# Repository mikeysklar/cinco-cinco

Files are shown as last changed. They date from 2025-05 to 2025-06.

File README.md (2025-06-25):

# Cinco-Cinco  
*A 5-Key Wireless Chording Keyboard*

Cinco-Cinco is a low-profile chording keyboard that uses just **five
keys** to emulate a full keyboard by combining keypresses into
chords and utilizing **seven layers**.

I’ve spent the last year building pocket keyboards. My
[BUBBY](https://github.com/mikeysklar/bubby) is a daily carry which
I use for todo lists. It made me enjoy typing with one hand to the
point that I wanted a desktop version, which is what you see here.

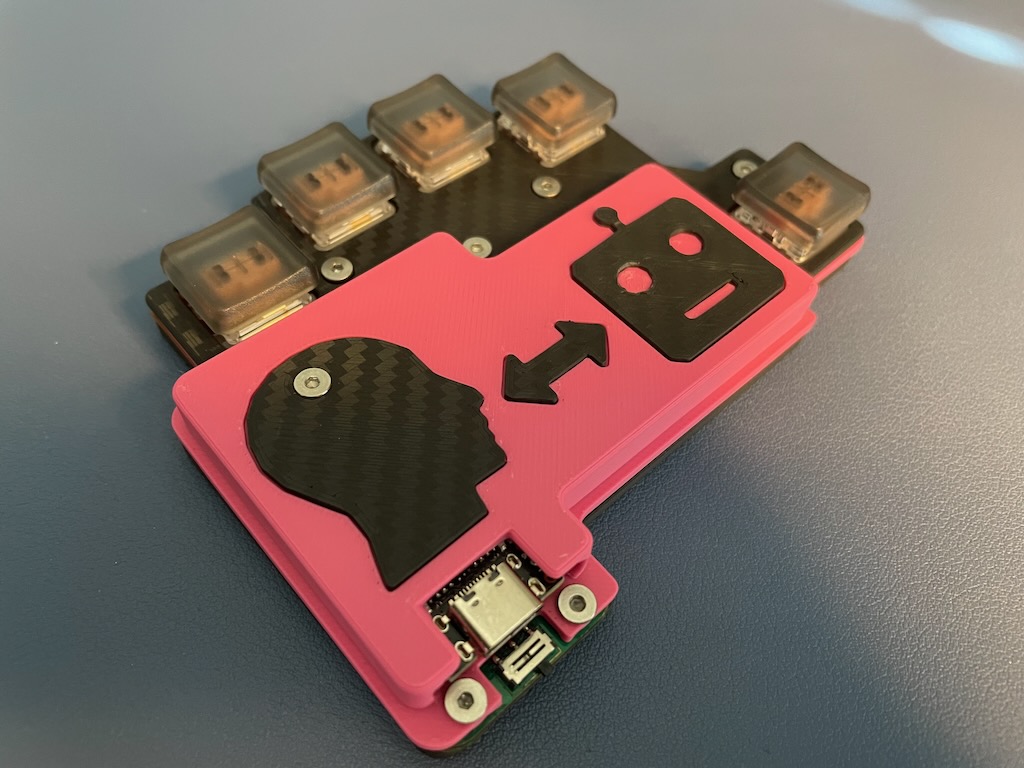
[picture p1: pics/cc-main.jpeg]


## Table of Contents

- [Introduction](#introduction)
- [Hardware Highlights](#hardware-highlights)
  - [Case Design](#case-design)
  - [Mechanical Switch Choice](#mechanical-switch-choice)
  - [Chording Software](#chording-software)
- [CircuitPython Compatibility](#circuitpython-compatibility)
- [Design Files & Software Versions](#design-files--software-versions)
- [Typing Speed](#typing-speed)
- [Layer Maps](#layer-maps)
  - [Layer 1: Letters](#layer-1-letters)
  - [Layer 2: Numbers](#layer-2-numbers)
  - [Layer 3: Whitespace & Delimiters](#layer-3-whitespace--delimiters)
  - [Layer 4: Modifiers & Navigation](#layer-4-modifiers--navigation)
  - [Layer 5: Mouse Control / Media](#layer-5-mouse-control--media)
  - [Layer 6: Media](#layer-6-media)
  - [Layer 7: F1 - F12](#layer-7-F1---F12)
- [BOM](#bill-of-materials)

---

## Introduction

Computing is rapidly changing. We are moving away from sitting at
desks and staring at screens. Smart glasses and watches let us
consume information on the go. Phones, which have taken too much
of our attention, no longer need to be our primary method of
communication.

**The keys are key**

Chording opens up a future of input that is compact, discreet, and
mobile. This same keyboard can also enhance desktop productivity,
allowing CAD users and creatives to use one hand for keyboard
shortcuts while the other handles precise mouse movements.

Cinco-Cinco uses just **five keys**, but can generate over 107
different key combos, including mouse actions. The thumb button
switches between **seven layers**—alphabets, numbers, punctuation,
and more. The layout is based on a modified SAIE layout, optimized so 
the most common letters require minimal finger effort.

At first, I wasn’t sure cramming so much into the thumb key would
work well. But with careful timing and logic in the firmware, it
switches layers smoothly without getting in the way.

---

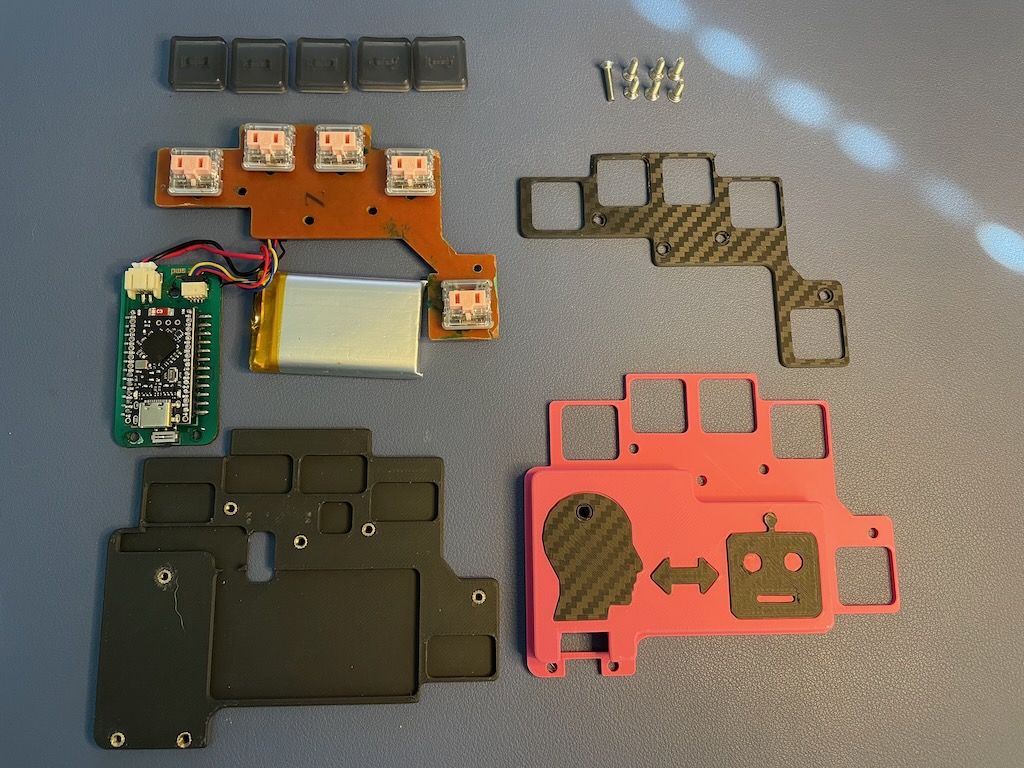
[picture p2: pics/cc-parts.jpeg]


## Hardware Highlights

- **I2C STEMMA QT connector** for plug-and-play support for different controllers  
- **Two PCB system**: one controller board and one keypad connected via STEMMA QT cable  
- **Hardware-based key detection**: MCP23008 GPIO expander running at 400 kHz for fast, accurate chord detection  
- **BLE-compatible microcontrollers**: Tested with nRF52840  
- **1200mAh battery** integrated into the case to hold keypad in place and reduce charging frequency  



### Case Design

The case is built as a three-layer sandwich. The base has cutouts
to keep components low profile and includes heat-set inserts to
secure the mid and top layers. The PCBs have matching holes for
alignment and locking, ensuring a secure fit.

Flat, countersunk screws keep the top flush. The “Human Machine”
inlay was added late to break up the large pink area and has become
a distinctive feature.

### Mechanical Switch Choice

I chose Kailh PG1350 CHOC switches for their availability and easy
installation. Their low-profile design lets all components fit on
the PCB’s bottom side, simplifying SMT assembly. I’ve tried pink,
red, and robin egg blue switches—the blue ones feel best to type
on, despite needing more force, and they look nice too.

### Chording Software

The firmware works hard to register chords accurately despite early
challenges with false triggers and duplicates. It waits for the
first key release before registering a chord, allowing for sloppy
or staggered key presses without mistakes. It doesn’t wait for all
keys to be released — once a key lifts, the chord buffer clears,
letting you move on quickly.

---

## CircuitPython Compatibility

- **Tested with CircuitPython**: Version 9.2.8
- Library installation process if MacOS is used (delete the ._ libs)

```
circup install adafruit_ble adafruit_bus_device adafruit_hid
cd /Volumes/CIRCUITPY
find . -type f -name '._*' -delete

circup install adafruit_displayio_ssd1306 adafruit_display_text adafruit_ssd1306 adafruit_mcp230xx

cd /Volumes/CIRCUITPY
find . -type f -name '._*' -delete
```

---

## Design Files & Software Versions

### PCB & Schematic Files
- **KiCad**: Version 9

**Cinco-Cinco board (`cinco-cinco/` folder):**
- [`cinco-cinco.kicad_sch`](cinco-cinco/cinco-cinco.kicad_sch)
- [`cinco-cinco.kicad_pcb`](cinco-cinco/cinco-cinco.kicad_pcb)

**nnv2-smd board (`nnv2-smd/` folder):**
- [`nnv2-smd.kicad_sch`](nnv2-smd/nnv2-smd.kicad_sch)
- [`nnv2-smd.kicad_pcb`](nnv2-smd/nnv2-smd.kicad_pcb)

### Case Files (`cad/` folder)
- **FreeCAD**: Version 1.x
- [`case.FCStd`](cad/case.FCStd)

**STL files for 3D printing:**
- [`case-top-cvr.stl`](cad/case-top-cvr.stl)
- [`case-mid-cvr.stl`](cad/case-mid-cvr.stl)
- [`case-lwr-cvr.stl`](cad/case-lwr-cvr.stl)

**STEP files for 3D viewing:**
- [`case-top-cvr.step`](cad/case-top-cvr.step)
- [`case-mid-cvr.step`](cad/case-mid-cvr.step)
- [`case-lwr-cvr.step`](cad/case-lwr-cvr.step)
- [`case-cinco-cinco.step`](cad/case-cinco-cinco.step)
- [`case-bat1200.step`](cad/case-bat1200.step)
- [`case-nnv2-smd.step`](cad/case-nnv2-smd.step)

All hardware design files are open source and located in the `pcb/` and `cad/` directories of this repository.

---

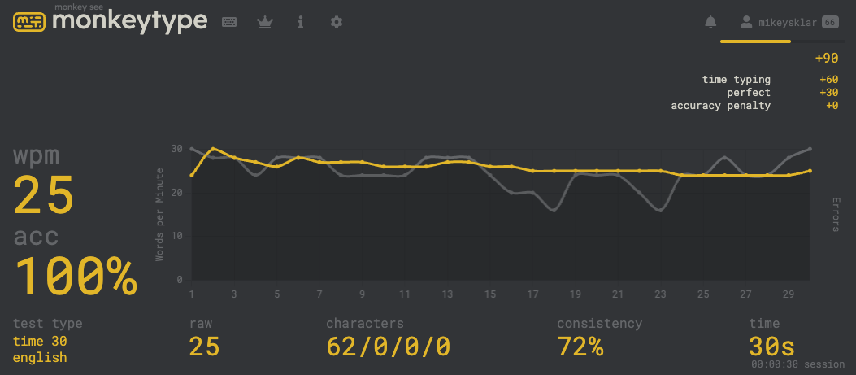
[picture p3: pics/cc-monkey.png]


## Typing Speed

Typing speed on the cinco is ~25 WPM. It is fast enough to not be frustrated. Slow enough to improve on.

That is about the same as my typing speed:

* thumb typing speed on my phone
* one handed on a qwerty full size keyboard

---

## Layer Maps

Each layer uses unique key combinations (chords) from the 5 keys (positions 0–4).

| Finger | Key Index |
|:---|:---|
| Thumb  | 4 |
| Pinky  | 3 |
| Ring | 2 |
| Middle | 1 |
| Fore | 0 |

## Layer 1: Letters 

| Key | Pky | Rng | Mid | Idx | Thm | Chord |
|---|:---:|:---:|:---:|:---:|:---:|---|
| A | |  x  | | | | (2,) |
| B |  x  | | | |  x  | (3,4) |
| C |  x  | | |  x  | | (0,3) |
| D | |  x  |  x  |  x  | | (0,1,2) |
| E | | | |  x  | | (0,) |
| F | |  x  |  x  | |  x  | (1,2,4) |
| G | | |  x  | |  x  | (1,4) |
| H | |  x  | | |  x  | (2,4) |
| I | | |  x  | | | (1,) |
| J | |  x  |  x  |  x  |  x  | (0,1,2,4) |
| K |  x  | |  x  | |  x  | (1,3,4) |
| L |  x  | |  x  | | | (1,3) |
| M | | | |  x  |  x  | (0,4) |
| N | |  x  |  x  | | | (1,2) |
| O | |  x  | |  x  | | (0,2) |
| P |  x  |  x  |  x  | | | (1,2,3) |
| Q |  x  |  x  |  x  |  x  |  x  | (0,1,2,3,4) |
| R | | |  x  |  x  | | (0,1) |
| S | | | | |  x  | (3,) |
| T |  x  |  x  | | | | (2,3) |
| U |  x  |  x  |  x  |  x  | | (0,1,2,3) |
| V |  x  |  x  | | |  x  | (2,3,4) |
| W | |  x  | |  x  |  x  | (0,2,4) |
| X |  x  | | |  x  |  x  | (0,3,4) |
| Y | | |  x  |  x  |  x  | (0,1,4) |
| Z |  x  |  x  |  x  | |  x  | (1,2,3,4) |
| BACKSPACE |  x  | |  x  |  x  | | (0,1,3) |
| SPACE |  x  |  x  | |  x  | | (0,2,3) |
    
## Layer 2: Numbers and Arrows 

| Action | Pky | Rng | Mid | Idx | Thm | Chord |
|---|:---:|:---:|:---:|:---:|:---:|---|
| ONE | | | |  X  | | (0,) |
| TWO | | |  X  | | | (1,) |
| THREE | |  X  | | | | (2,) |
| FOUR |  X  | | | | | (3,) |
| FIVE | | |  X  |  X  | | (0, 1) |
| SIX | |  X  |  X  | | | (1, 2) |
| SEVEN |  X  |  X  | | | | (2, 3) |
| EIGHT | |  X  | |  X  | | (0, 2) |
| NINE |  X  | |  X  | | | (1, 3) |
| ZERO | |  X  |  X  |  X  | | (0, 1, 2) |
| UP_ARROW | | | |  X  |  X  | (0, 4) |
| DOWN_ARROW  | | |  X  | |  X  | (1, 4) |
| RIGHT_ARROW | |  X  | | |  X  | (2, 4) |
| LEFT_ARROW  |  X  | | | |  X  | (3, 4) |
| PAGE_UP | | |  X  |  X  |  X  | (0, 1, 4) |
| PAGE_DOWN |  X  |  X  | | |  X  | (2, 3, 4) |
| END | |  X  |  X  |  X  |  X  | (0, 1, 2, 4) |
| DELETE | |  X  | |  X  |  X  | (0, 2, 4) |
| INSERT |  X  | |  X  | |  X  | (1, 3, 4) |
| HOME |  X  |  X  |  X  | |  X  | (1, 2, 3, 4) |

## Layer 3: Whitespace & Delimiters

| Action | Pky | Rng | Mid | Idx | Thm | Chord |
| --- | :-: | :-: | :-: | :-: | :-: | --- |
| ESCAPE | | | |  X  | | (0,) |
| TAB | | |  X  | | | (1,) |
| PERIOD | |  X  | | | | (2,) |
| MINUS |  X  | | | | | (3,) |
| FORWARD_SLASH  |  X  |  X  | | | | (2, 3) |
| ENTER | | |  X  |  X  | | (0, 1) |
| COMMA | |  X  | |  X  | | (0, 2) |
| LEFT_BRACKET |  X  | |  X  | | | (1, 3) |
| RIGHT_BRACKET  |  X  | | |  X  | | (0, 3) |
| BACKSLASH |  X  |  X  |  X  | | | (1, 2, 3) |
| BACKSPACE | |  X  |  X  | | | (1, 2) |
| QUOTE |  X  | |  X  |  X  | | (0, 1, 3) |
| SEMICOLON |  X  |  X  | |  X  | | (0, 2, 3) |
| GRAVE_ACCENT |  X  |  X  |  X  |  X  | | (0, 1, 2, 3)  |
| DELETE | |  X  |  X  |  X  | | (0, 1, 2) |

## Layer 4: Modifiers & Navigation (SCAG)

| Action | Pky | Rng | Mid | Idx | Thm | Chord |
| --- | :-: | :-: | :-: | :-: | :-: | --- |
| LEFT_SHIFT |  X  | | | | | (3,) |
| LEFT_CONTROL | |  X  | | | | (2,) |
| LEFT_ALT | | |  X  | | | (1,) |
| LEFT_GUI | | | |  X  | | (0,) |
| RIGHT_ALT (⌥)  | | |  X  |  X  | | (0, 1)  |

## Layer 5: Mouse Control (Movement, Scroll, Buttons)

| Action | Pky | Rng | Mid | Idx | Thm | Chord |
| --- | :-: | :-: | :-: | :-: | :-: | --- |
| MOVE UP | | | |  X  |  X  | (0, 4) |
| MOVE DOWN | | |  X  | |  X  | (1, 4) |
| MOVE RIGHT | |  X  | | |  X  | (2, 4) |
| MOVE LEFT |  X  | | | |  X  | (3, 4) |
| SCROLL UP | | |  X  |  X  |  X  | (0, 1, 4) |
| SCROLL DOWN |  X  |  X  | | |  X  | (2, 3, 4) |
| LEFT CLICK |  X  |  X  | | | | (3, 2) |
| RIGHT CLICK | | |  X  |  X  | | (0, 1) |
| MIDDLE CLICK | | |  X  | | | (1, 1) |
| FORWARD CLICK  |  X  | | |  X  | | (0, 3) |
| HOLD LEFT | |  X  |  X  |  X  | | (0, 1, 2) |
| RELEASE LEFT |  X  | |  X  |  X  | | (0, 1, 3) |
| ACCELERATE |  X  |  X  |  X  | | | (1, 2, 3) |

## Layer 6: Media

| Action | Pky | Rng | Mid | Idx | Thm | Chord |
| --- | :-: | :-: | :-: | :-: | :-: | --- |
| BRIGHTNESS_DECREMENT | | | |  X  | | (0,) |
| BRIGHTNESS_INCREMENT | | |  X  | | | (1,) |
| VOLUME_DECREMENT | |  X  | | | | (2,) |
| VOLUME_INCREMENT |  X  | | | | | (3,) |
| MUTE | | |  X  |  X  | | (0, 1) |
| PLAY_PAUSE |  X  |  X  | | | | (2, 3) |
| SCAN_NEXT_TRACK | |  X  | |  X  | | (0, 2) |
| SCAN_PREVIOUS_TRACK  |  X  | |  X  | | | (1, 3) |
| FAST_FORWARD |  X  | | |  X  | | (0, 3) |
| REWIND | |  X  |  X  | | | (1, 2) |
| STOP | |  X  |  X  |  X  | | (0, 1, 2) |
| EJECT |  X  | |  X  |  X  | | (0, 1, 3) |

## Layer 7: F1 - F12

| Action | Pky | Rng | Mid | Idx | Thm | Chord |
| --- | :-: | :-: | :-: | :-: | :-: | --- |
| F1 | | | |  X  | | (0,) |
| F2 | | |  X  | | | (1,) |
| F3 | |  X  | | | | (2,) |
| F4 |  X  | | | | | (3,) |
| F5 | | |  X  |  X  | | (0, 1) |
| F6 | |  X  |  X  | | | (1, 2) |
| F7 |  X  |  X  | | | | (2, 3) |
| F8 | |  X  | |  X  | | (0, 2) |
| F9 |  X  | |  X  | | | (1, 3) |
| F10 | |  X  |  X  |  X  | | (0, 1, 2) |
| F11 |  X  |  X  |  X  | | | (1, 2, 3) |
| F12 |  X  |  X  | |  X  | | (0, 2, 3) |

---

## Bill of Materials

cinco-cinco keypad

| Designators | Qty | Value | Footprint |
|---|-----|---|---|
| R1–R4 | 4 | 10 kΩ | SMD 0805 resistor |
| J1 | 1 | Conn_01x04_Socket | JST-SH 4-pin connector |
| U1 | 1 | MCP23008-xSS | SSOP-20 package |
| SW1–SW5 | 5 | SW_Push | Kailh PG1350 switch socket|
| JP1 | 1 | SolderJumper_2_Open | 2-pin solder jumper |

BLE Controller Breakout nRF52840 Nice Nano v2

| Designators | Qty | Value | Footprint |
|---|-----|---|---|
| U1 | 1 | Nice!Nano v2 | SuperMini nRF52840 |
| J2 | 1 | Conn_01x04_Socket | JST-SH 4-pin connector |
| J1 | 1 | Conn_01x02_Socket | JST-PH 2-pin connector |
| SW1 | 1 | SW_SPST | SMD slide switch |

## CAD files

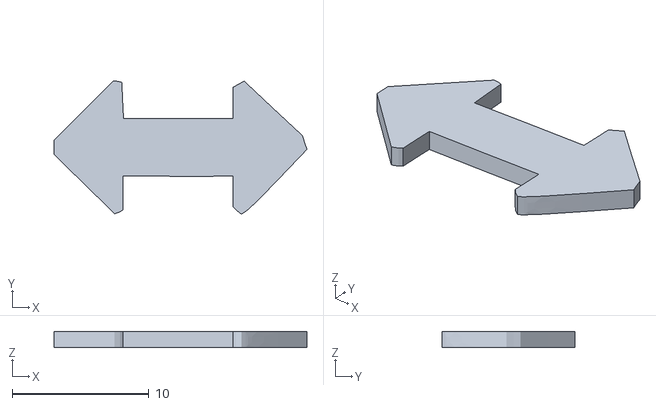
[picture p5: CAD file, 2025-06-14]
cad/case-arrow.stl
18.5 x 9.74 x 1.20

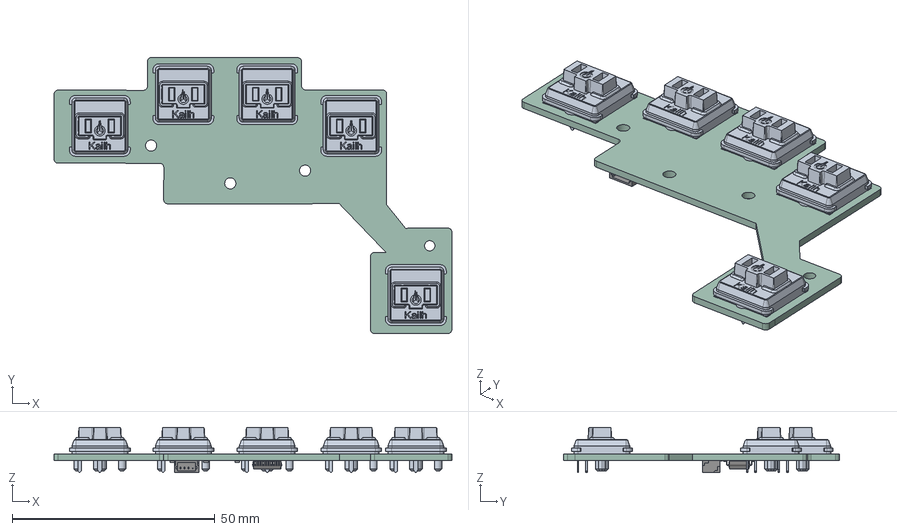
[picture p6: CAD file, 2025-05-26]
cinco-cinco/cinco-cinco.step
98.1 x 68.1 x 11.1 mm
Kailh LP Choc Burnt Orange x 5
R_0805_2012Metric x 4
SSOP-20_5.3x7.2mm_P0.65mm
SPARKFUN_QWIIC_RIGHT_ANGLE
cinco-cinco_copper
cinco-cinco_pad
cinco-cinco_silkscreen
cinco-cinco_PCB

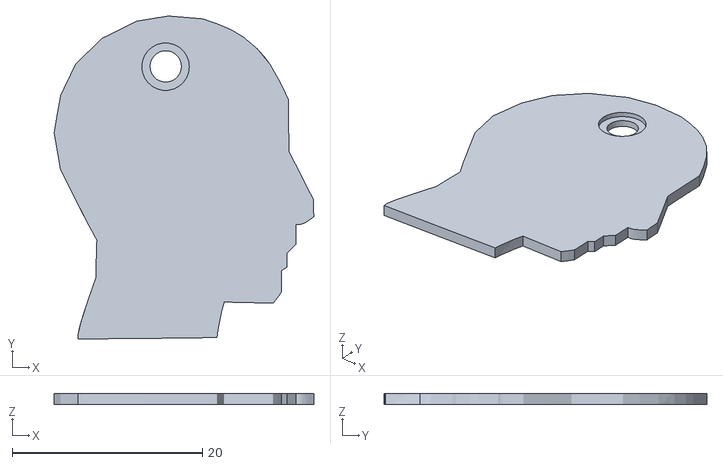
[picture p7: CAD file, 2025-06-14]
cad/case-human.stl
27.3 x 34.0 x 1.20

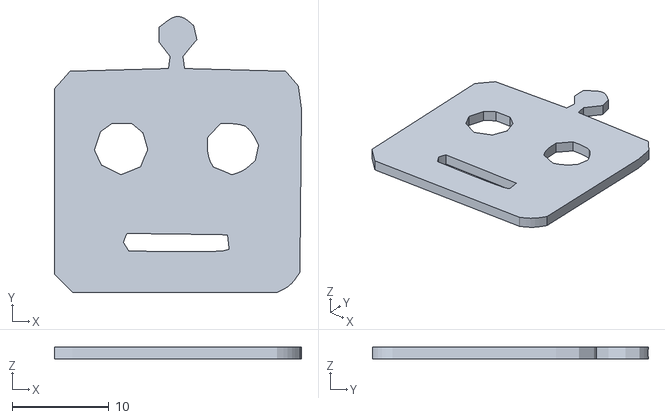
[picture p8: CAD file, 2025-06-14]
cad/case-robot.stl
25.5 x 28.5 x 1.20

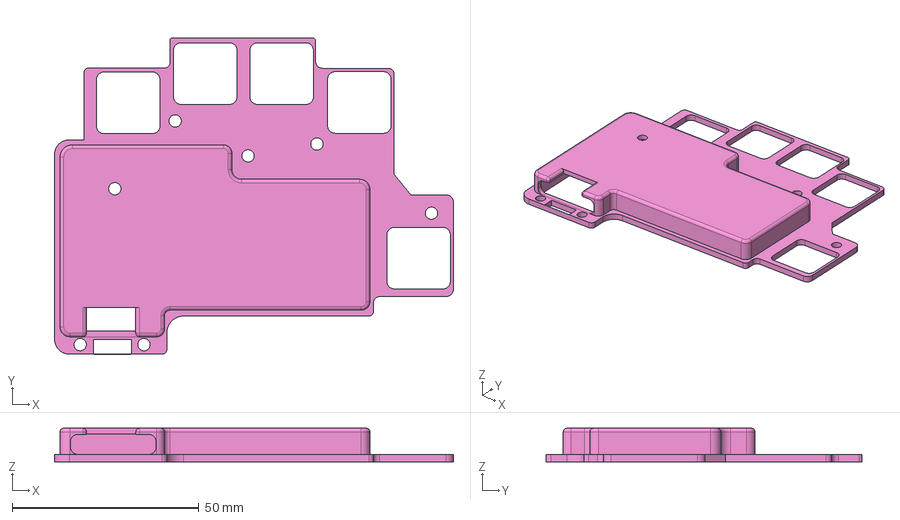
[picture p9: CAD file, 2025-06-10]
cad/case-mid-cvr.step
106.9 x 84.8 x 9.00 mm

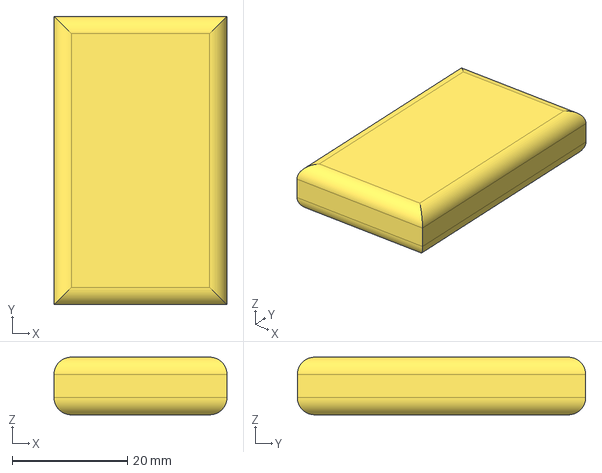
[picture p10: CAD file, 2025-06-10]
cad/case-bat1200.step
30.0 x 50.0 x 10.0 mm

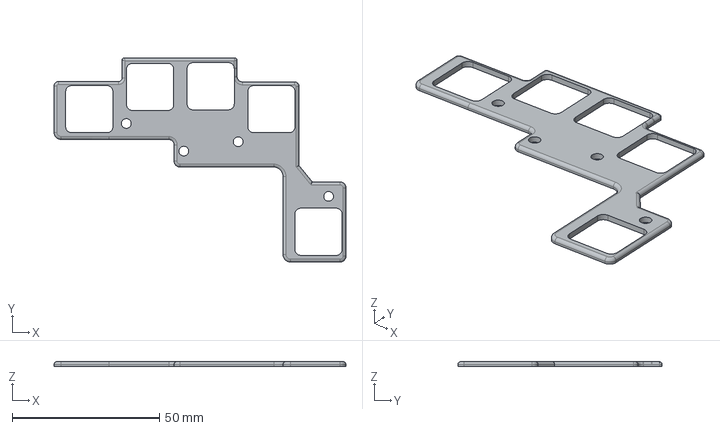
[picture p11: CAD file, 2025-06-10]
cad/case-top-cvr.step
99.1 x 69.3 x 1.60 mm

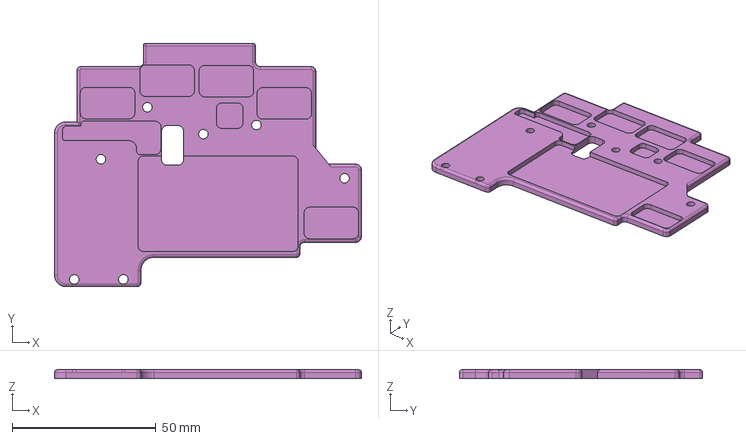
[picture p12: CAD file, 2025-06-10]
cad/case-lwr-cvr.step
106.9 x 84.8 x 3.00 mm

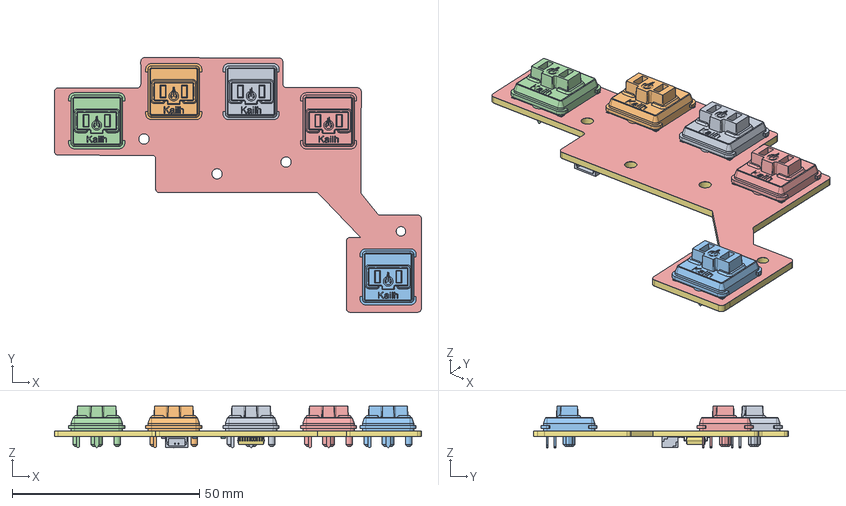
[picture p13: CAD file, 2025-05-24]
cad/case.FCStd
98.1 x 68.1 x 11.1 mm
Kailh LP Choc Burnt Orange
Kailh LP Choc Burnt Orange001
Kailh LP Choc Burnt Orange002
Kailh LP Choc Burnt Orange003
Kailh LP Choc Burnt Orange004
R_0805_2012Metric
SSOP-20_5.3x7.2mm_P0.65mm
R_0805_2012Metric001
SPARKFUN_QWIIC_RIGHT_ANGLE
R_0805_2012Metric002
R_0805_2012Metric003
cinco-cinco_copper
cinco-cinco_copper001
cinco-cinco_copper002
cinco-cinco_copper003
cinco-cinco_copper004
cinco-cinco_copper005
cinco-cinco_copper006
cinco-cinco_copper007
cinco-cinco_copper008
cinco-cinco_copper009
cinco-cinco_pad
cinco-cinco_pad001
cinco-cinco_pad002
cinco-cinco_pad003
cinco-cinco_pad004
cinco-cinco_pad005
cinco-cinco_pad006
cinco-cinco_pad007
cinco-cinco_pad008
cinco-cinco_pad009
cinco-cinco_pad010
cinco-cinco_pad011
cinco-cinco_pad012
cinco-cinco_pad013
cinco-cinco_pad014
cinco-cinco_pad015
cinco-cinco_pad016
cinco-cinco_pad017
cinco-cinco_pad018
cinco-cinco_pad019
cinco-cinco_pad020
cinco-cinco_pad021
cinco-cinco_pad022
cinco-cinco_pad023
cinco-cinco_pad024
cinco-cinco_pad025
cinco-cinco_pad026
cinco-cinco_pad027
cinco-cinco_pad028
cinco-cinco_pad029
cinco-cinco_pad030
cinco-cinco_pad031
cinco-cinco_pad032
cinco-cinco_pad033
cinco-cinco_pad034
cinco-cinco_pad035
cinco-cinco_pad036
cinco-cinco_pad037
cinco-cinco_pad038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

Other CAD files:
cad/case-lwr-cvr.stl
cad/case-mid-cvr.stl
cad/case-top-cvr.stl

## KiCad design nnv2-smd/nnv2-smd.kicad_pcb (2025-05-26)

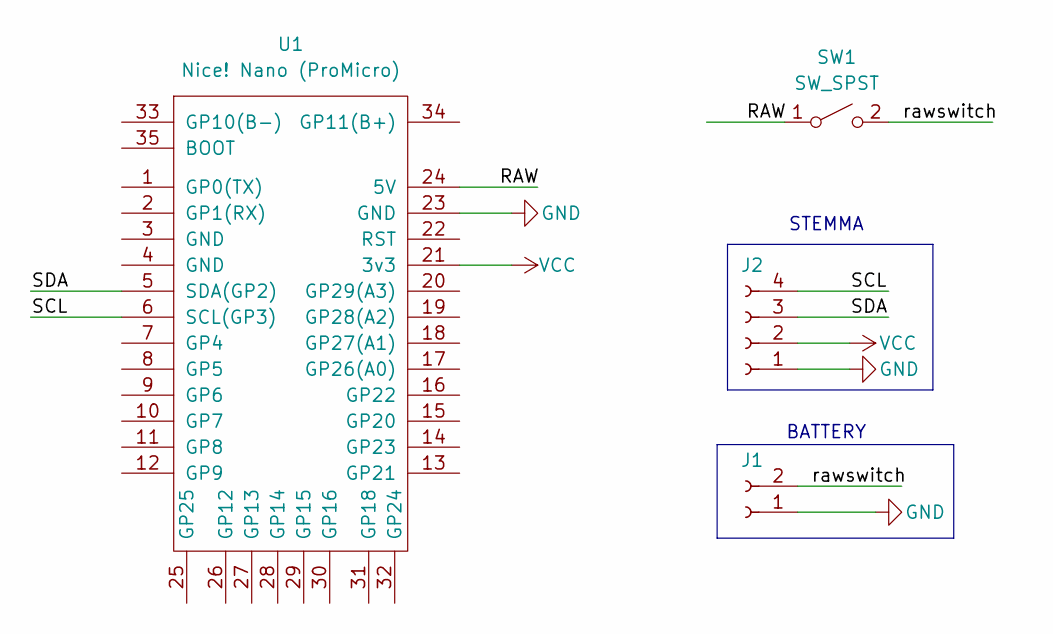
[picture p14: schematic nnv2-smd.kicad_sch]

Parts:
J1: Conn_01x02_Socket; JST_PH_S2B-PH-SM4-TB_1x02-1MP_P2.00mm_Horizontal
J2: Conn_01x04_Socket; JST_SH_SM04B-SRSS-TB_1x04-1MP_P1.00mm_Horizontal
SW1: SW_SPST; slide-switch-smd
U1: Nice! Nano (ProMicro); nnv2-mod

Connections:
/RAW: SW1.1 (A), U1.24 (5V)
/SCL: J2.4, U1.6 (SCL(GP3))
/SDA: J2.3, U1.5 (SDA(GP2))
/rawswitch: J1.2, SW1.2 (B)
GND: J1.1, J2.1, U1.23 (GND)
VCC: J2.2, U1.21 (3v3)

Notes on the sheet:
BATTERY
STEMMA

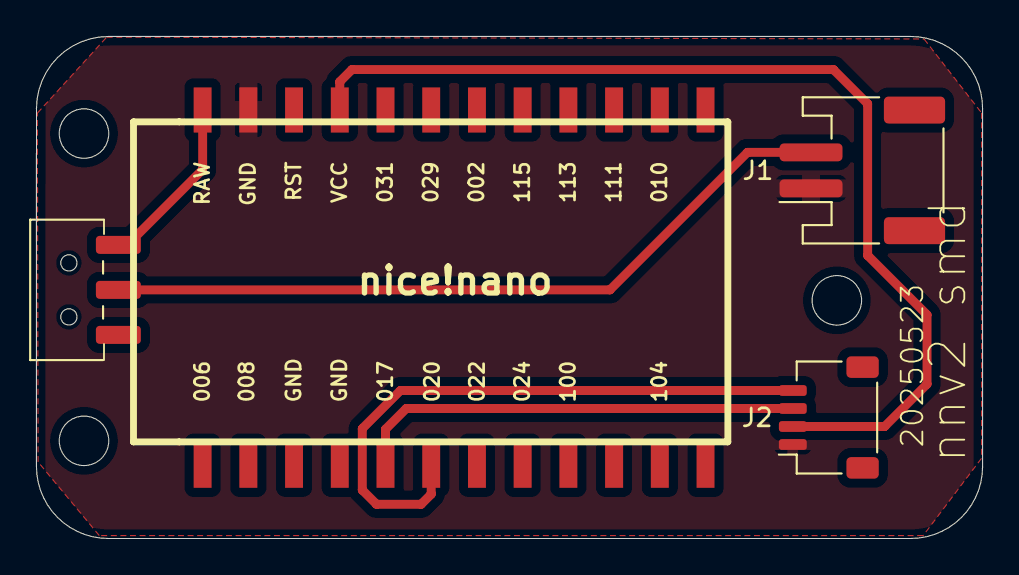
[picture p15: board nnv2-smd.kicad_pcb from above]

Board: 2 copper layers, 52.6 x 27.9 mm, 4 parts (0 on the bottom side), 6 nets.

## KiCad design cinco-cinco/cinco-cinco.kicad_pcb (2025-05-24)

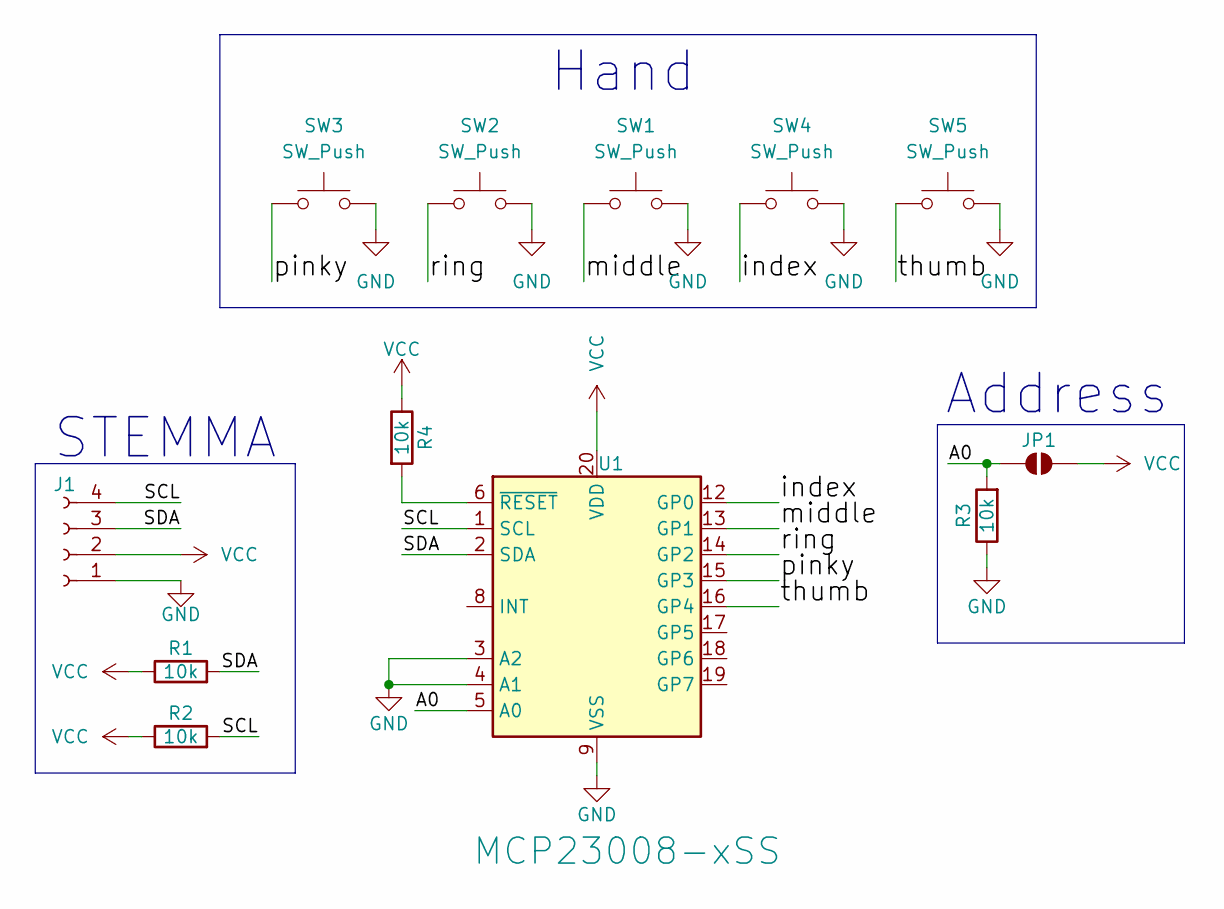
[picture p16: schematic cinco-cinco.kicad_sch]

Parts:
J1: Conn_01x04_Socket; JST_SH_SM04B-SRSS-TB_1x04-1MP_P1.00mm_Horizontal
JP1: SolderJumper_2_Open; SolderJumper-2_P1.3mm_Open_TrianglePad1.0x1.5mm
R1, R2, R3, R4: 10k; R_0805_2012Metric_Pad1.20x1.40mm_HandSolder
SW1, SW2, SW3, SW4, SW5: SW_Push; Kailh_socket_PG1350
U1: MCP23008-xSS; SSOP-20_5.3x7.2mm_P0.65mm

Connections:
/A0: JP1.1 (A), R3.2, U1.5 (A0)
/SCL: J1.4, R2.2, U1.1 (SCL)
/SDA: J1.3, R1.2, U1.2 (SDA)
/index: SW4.1, U1.12 (GP0)
/middle: SW1.1, U1.13 (GP1)
/pinky: SW3.1, U1.15 (GP3)
/ring: SW2.1, U1.14 (GP2)
/thumb: SW5.1, U1.16 (GP4)
GND: J1.1, R3.1, SW1.2, SW2.2, SW3.2, SW4.2, SW5.2, U1.3 (A2), U1.4 (A1), U1.9 (VSS)
unnamed: R4.2, U1.6 (~RESET)
VCC: J1.2, JP1.2 (B), R1.1, R2.1, R4.1, U1.20 (VDD)

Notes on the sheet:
STEMMA
Hand
Address

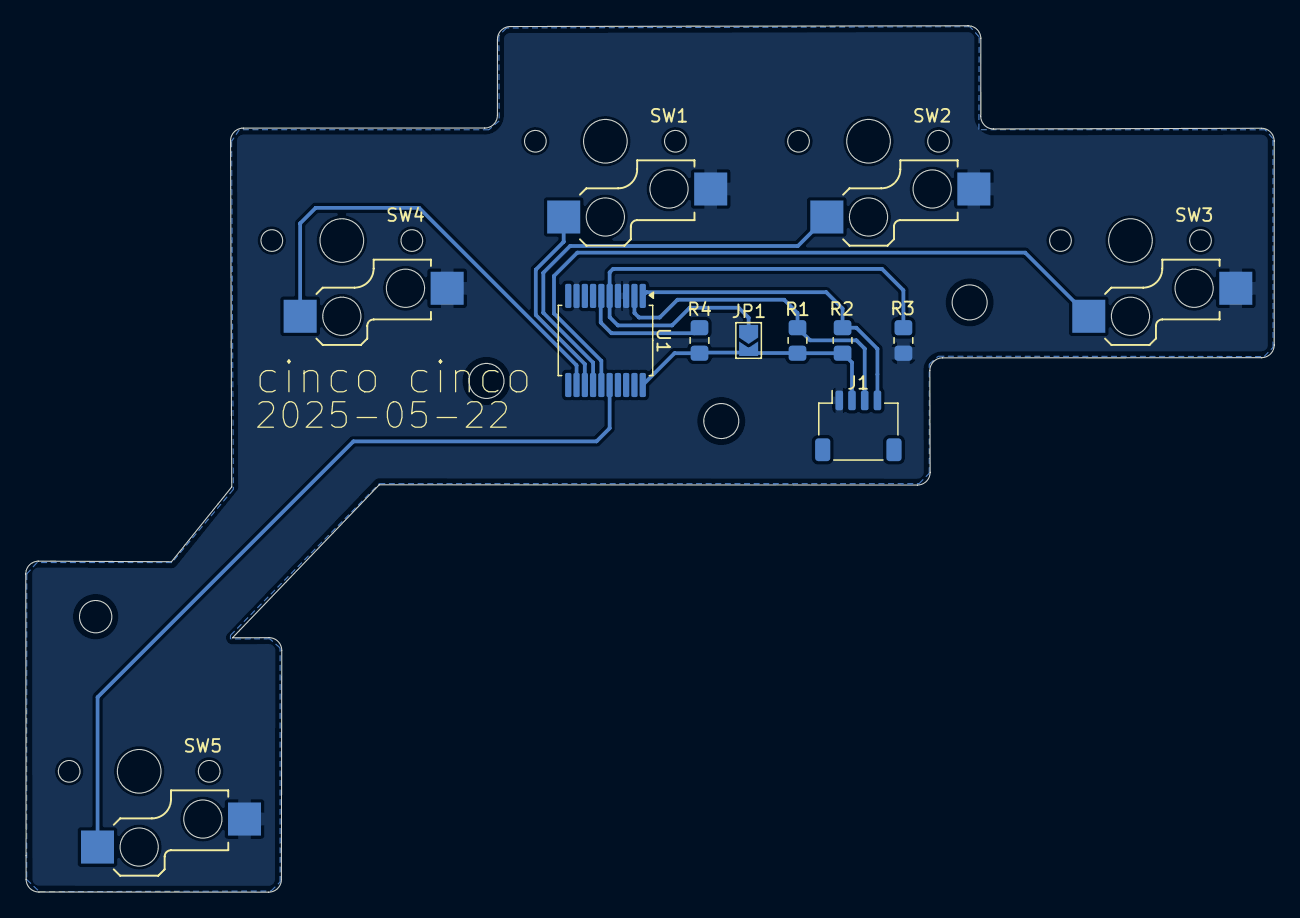
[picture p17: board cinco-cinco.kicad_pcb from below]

Board: 2 copper layers, 98.1 x 68.1 mm, 12 parts (7 on the bottom side), 11 nets.

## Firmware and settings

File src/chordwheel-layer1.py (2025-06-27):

import matplotlib.pyplot as plt
import numpy as np
from matplotlib.lines import Line2D

# Define finger data and visualization settings
fingers = ['Pinky', 'Ring', 'Middle', 'Index', 'Thumb']
finger_colors = ['#d62728', '#ff7f0e', '#ffdb58', '#2ca02c', '#1f77b4']
finger_markers = ['o', 's', '^', 'D', '*']

# Chord data: fingers pressed per letter (P, R, M, I, T)
chords = {
    'A': [0,1,0,0,0],
    'B': [1,0,0,0,1],
    'C': [1,0,0,1,0],
    'D': [0,1,1,1,0],
    'E': [0,0,1,0,0],
    'F': [0,1,1,0,1],
    'G': [0,0,1,0,1],
    'H': [0,1,0,0,1],
    'I': [0,0,1,0,0],
    'J': [0,1,1,1,1],
    'K': [1,0,1,0,1],
    'L': [1,0,1,0,0],
    'M': [0,0,1,0,1],
    'N': [0,1,1,0,0],
    'O': [0,1,0,1,0],
    'P': [1,1,1,0,0],
    'Q': [1,1,1,1,1],
    'R': [0,0,1,1,0],
    'S': [0,0,0,0,1],
    'T': [1,1,0,0,0],
    'U': [1,1,1,1,0],
    'V': [1,1,0,0,1],
    'W': [0,1,0,1,1],
    'X': [1,0,0,1,1],
    'Y': [0,0,1,1,1],
    'Z': [1,1,1,0,1]
}

num_chords = len(chords)
angle_per_chord = 2 * np.pi / num_chords

fig, ax = plt.subplots(figsize=(10,10), subplot_kw=dict(polar=True))
ax.set_theta_zero_location('N')
ax.set_theta_direction(-1)
ax.set_ylim(0, 7)

ring_radii = [2, 3, 4, 5, 6]

# Draw colored concentric rings
for i, r in enumerate(ring_radii):
    ax.fill_between(np.linspace(0, 2*np.pi, 500), r, r+0.7, 
                    color=finger_colors[i], alpha=0.15)

# Draw radial lines separating wedges
for i in range(num_chords):
    angle = i * angle_per_chord
    ax.plot([angle, angle], [ring_radii[0], ring_radii[-1] + 0.7], color='lightgray', lw=0.8)

# Plot finger dots
for i, (letter, fingers_pressed) in enumerate(chords.items()):
    angle = i * angle_per_chord + angle_per_chord / 2
    for j, pressed in enumerate(fingers_pressed):
        if pressed:
            ax.plot(angle, ring_radii[j] + 0.35, finger_markers[j], markersize=18, 
                    color=finger_colors[j], markeredgecolor='k', markeredgewidth=0.8)

# Letter labels
label_radius = ring_radii[-1] + 1.1
for i, letter in enumerate(chords.keys()):
    angle = i * angle_per_chord + angle_per_chord / 2

    ha = 'center'
    if np.pi / 4 < angle < 3 * np.pi / 4:
        ha = 'center'
    elif 3 * np.pi / 4 <= angle <= 5 * np.pi / 4:
        ha = 'right'
    elif 5 * np.pi / 4 < angle < 7 * np.pi / 4:
        ha = 'center'
    else:
        ha = 'left'

    ax.text(angle, label_radius, letter, fontsize=16, fontweight='bold',
            horizontalalignment=ha, verticalalignment='center')

# Smaller legend/key below the plot
legend_elements = [Line2D([0], [0], marker=m, color='w', label=f, 
                          markerfacecolor=c, markeredgecolor='k', markersize=12, markeredgewidth=0.8) 
                   for m, c, f in zip(finger_markers, finger_colors, fingers)]

ax.legend(handles=legend_elements, loc='lower center', bbox_to_anchor=(0.5, -0.1),
          fontsize=12, frameon=False, ncol=5, title="Fingers")

ax.legend_.get_title().set_fontsize('14')
ax.legend_.get_title().set_fontweight('bold')

ax.grid(False)
ax.set_xticks([])
ax.set_yticks([])

plt.savefig("chord_wheel_clean.svg", format="svg", bbox_inches='tight')
plt.show()

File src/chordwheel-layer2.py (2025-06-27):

import matplotlib.pyplot as plt
import numpy as np
from matplotlib.lines import Line2D

# Layer 2 chords with correct finger presses
chords_layer2 = {
    'ONE':       [0, 0, 0, 1, 0],      # Idx
    'TWO':       [0, 0, 1, 0, 0],      # Mid
    'THREE':     [0, 1, 0, 0, 0],      # Rng
    'FOUR':      [1, 0, 0, 0, 0],      # Pky
    'FIVE':      [0, 0, 1, 1, 0],      # Mid, Idx
    'SIX':       [0, 1, 1, 0, 0],      # Rng, Mid
    'SEVEN':     [1, 1, 0, 0, 0],      # Pky, Rng
    'EIGHT':     [0, 0, 1, 1, 0],      # Mid, Idx
    'NINE':      [1, 0, 1, 0, 0],      # Pky, Mid
    'ZERO':      [1, 1, 1, 0, 0],      # Pky, Rng, Mid
    'UP_ARROW':  [0, 0, 0, 1, 1],      # Idx, Thm
    'DOWN_ARROW':[0, 0, 1, 0, 1],      # Mid, Thm
    'RIGHT_ARROW':[0, 1, 0, 0, 1],     # Rng, Thm
    'LEFT_ARROW':[1, 0, 0, 0, 1],      # Pky, Thm
    'PAGE_UP':   [0, 0, 1, 1, 1],      # Mid, Idx, Thm
    'PAGE_DOWN': [1, 1, 0, 0, 1],      # Pky, Rng, Thm
    'END':       [1, 1, 1, 1, 0],      # Pky, Rng, Mid, Idx
    'DELETE':    [1, 0, 1, 1, 0],      # Pky, Mid, Idx
    'INSERT':    [1, 0, 1, 0, 1],      # Pky, Mid, Thm
    'HOME':      [1, 1, 1, 0, 1],      # Pky, Rng, Mid, Thm
}

fingers = ['Pinky', 'Ring', 'Middle', 'Index', 'Thumb']
finger_colors = ['#d62728', '#ff7f0e', '#ffdb58', '#2ca02c', '#1f77b4']  # red, orange, yellow, green, blue
finger_markers = ['o', 's', '^', 'D', '*']  # circle, square, triangle_up, diamond, star

num_chords = len(chords_layer2)
angle_per_chord = 2 * np.pi / num_chords

fig, ax = plt.subplots(figsize=(12,12), subplot_kw=dict(polar=True))
ax.set_theta_zero_location('N')
ax.set_theta_direction(-1)
ax.set_ylim(0, 7)

ring_radii = [2, 3, 4, 5, 6]  # concentric rings Pinky (2) to Thumb (6)

# Draw colored rings for fingers
for i, r in enumerate(ring_radii):
    ax.fill_between(np.linspace(0, 2*np.pi, 500), r, r+0.7,
                    color=finger_colors[i], alpha=0.15)

# Radial separators between wedges
for i in range(num_chords):
    angle = i * angle_per_chord
    ax.plot([angle, angle], [ring_radii[0], ring_radii[-1]+0.7], color='lightgray', lw=0.8)

# Plot finger dots per chord
for i, (label, pressed) in enumerate(chords_layer2.items()):
    angle = i * angle_per_chord + angle_per_chord/2
    for j, val in enumerate(pressed):
        if val:
            ax.plot(angle, ring_radii[j] + 0.35, finger_markers[j], markersize=18,
                    color=finger_colors[j], markeredgecolor='k', markeredgewidth=0.8)

# Letter labels outside the outer ring
label_radius = ring_radii[-1] + 1.1
for i, label in enumerate(chords_layer2.keys()):
    angle = i * angle_per_chord + angle_per_chord/2
    ha = 'center'
    if np.pi/4 < angle < 3*np.pi/4:
        ha = 'center'
    elif 3*np.pi/4 <= angle <= 5*np.pi/4:
        ha = 'right'
    elif 5*np.pi/4 < angle < 7*np.pi/4:
        ha = 'center'
    else:
        ha = 'left'
    ax.text(angle, label_radius, label, fontsize=12, fontweight='bold',
            horizontalalignment=ha, verticalalignment='center')

# Legend below the wheel
legend_elements = [Line2D([0], [0], marker=m, color='w', label=f,
                          markerfacecolor=c, markeredgecolor='k', markersize=12, markeredgewidth=0.8)
                   for m, c, f in zip(finger_markers, finger_colors, fingers)]

ax.legend(handles=legend_elements, loc='lower center', bbox_to_anchor=(0.5, -0.1),
          fontsize=12, frameon=False, ncol=5, title="Fingers")

# Remove grid and ticks
ax.grid(False)
ax.set_xticks([])
ax.set_yticks([])

plt.savefig("chord_wheel_layer2_corrected.svg", format="svg", bbox_inches='tight')
plt.show()

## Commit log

2025-05-21 c5k kicad prototype
    [cinco-cinco.kicad_pcb, cinco-cinco.kicad_sch]
2025-05-24 so much new schtuff.
    [case.FCStd, cinco-cinco-B_Cu-m.dxf, cinco-cinco-B_Cu.dxf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]
2025-05-26 cad step case
    [cinco-cinco-B_Mask-m.dxf, cinco-cinco-B_Silkscreen-m.dxf, cinco-cinco.step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]
2025-05-28 case / code
    case looks good and went together well..
    code works well first three layers in. locking and fast.
    [case-bu-case.stl, case-fu-case.stl]
2025-06-07 top cover
    added MCU and BAT covers, lots of room and thick walled 1.6mm
    [case-bat-cover.stl, case-bu-case.step, case-bu-case.stl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]
2025-06-10 cleanup / regen design files
    [case-bat-cover.stl, case-bat1200.step, case-bu-case.step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]
2025-06-14 added some shiznat
    [case-arrow.stl, case-human.stl, case-mid-cvr.stl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]
2025-06-17 broke out chord map into separate file
    [c5k-left.py]
2025-06-18 navigation key changes
    * added thumb support to all layers
    * collapsed navigation keys into layer-2
    * added web navigation layer
    * web nav has some issues passing mulitple variables. Need to update code.
    Now Freecad and Kicad layers can be added.
    [c5k-left.py]
2025-06-20 layer-6 sticky
    media keys get stuck due to raw keycdoes going through.
    [c5k-left.py]
2025-06-23 readme
    bom, re-order readme, write-up
